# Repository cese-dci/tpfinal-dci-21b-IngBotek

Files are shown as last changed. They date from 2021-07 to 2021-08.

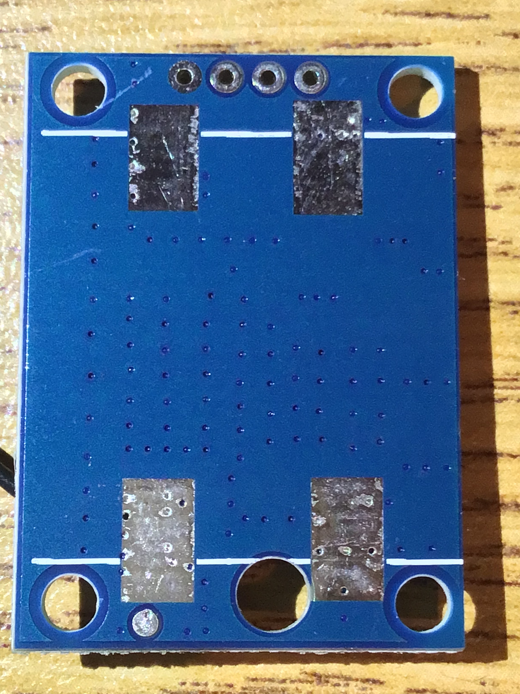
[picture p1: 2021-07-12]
doc/propuesta/Posterior.jpeg

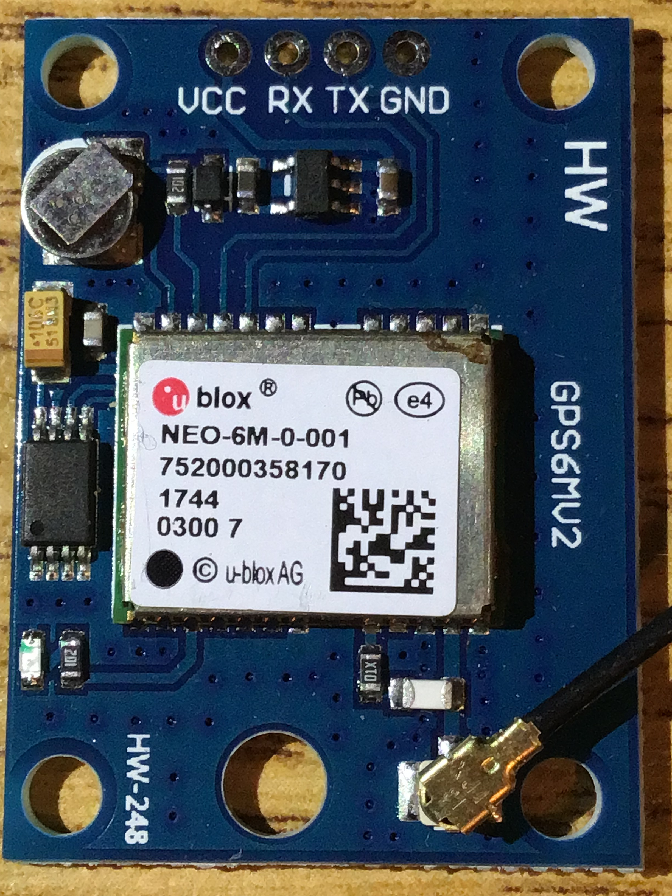
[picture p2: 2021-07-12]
doc/propuesta/Superior.jpeg

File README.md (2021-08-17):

## Trabajo práctico final de la asignatura DCI ##
Este repositorio contiene el trabajo práctico final para la asignatura de Diseño de Circuitos Impresos de la carrera de posgrado de FIUBA.

* Autor: Christian Canaan Castro Botek
* Título corto del trabajo:  Replica ublox NEO-6M GPS module
* Descripción: Módulo receptor que puede ser utilizado en cualquier aplicación que requiera geolocalización, cuenta con una antena de gran potencia, posee una memoria EEPROM para guardar datos y una batería para respaldar la configuración del módulo. Es compatible con Arduino, PIC, AVR, Raspberry y otros microcontroladores.

## Licencia de este trabajo ##
XXXMENCIONAR ACÁ LA LICENCIAXXX (Editar este párrafo) 
Y además colcar el archivo de texto de la misma en el directorio raíz.
Para este TP se pide que la licencia sea de hardware abierto.
Ver la sección "What license should I use?": https://www.oshwa.org/faq/

## Estructura del TP FINAL ##

Se propone y se pide utilizar la siguiente estructura.

* doc: Toda la información sobre el circuito, principalmente de autoría o procesamiento propio. Por ejemplo:
  * Notas de ingeniería propias.
  * Notas de aplicación propias.
  * Estudios previos, estado del arte, resumen de las investigaciones.
  * Notas con cálculos.
  * Dibujos adicionales.
  * Fotos de los prototipos.
  * Presupuestos, cotizaciones.
* info: Toda la iformación recolectada, principalmente de terceros, como por ejemplo:
  * Hojas de datos.
  * Notas de aplicación.
  * Info de productos comerciales.
  * Info en internet.
* pcb: Archivos de diseño esquemático y pcb.

Dependiendo la magnitud del proyecto, tendremos más o menos información en estos directorios. 
Revisar los README.md en cada directorio para conocer las pautas de cada uno para este TP.

NOTA: El alumno puede y debe borrar de este archivo todo lo que considere necesario, por ejemplo las aclaraciones del docente y esta misma nota.

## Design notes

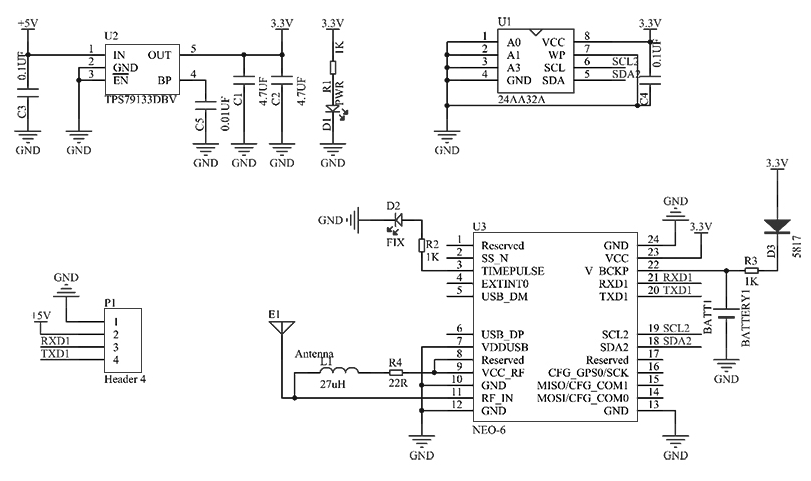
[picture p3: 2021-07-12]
doc/propuesta/Esquemático - NEO-6M.png

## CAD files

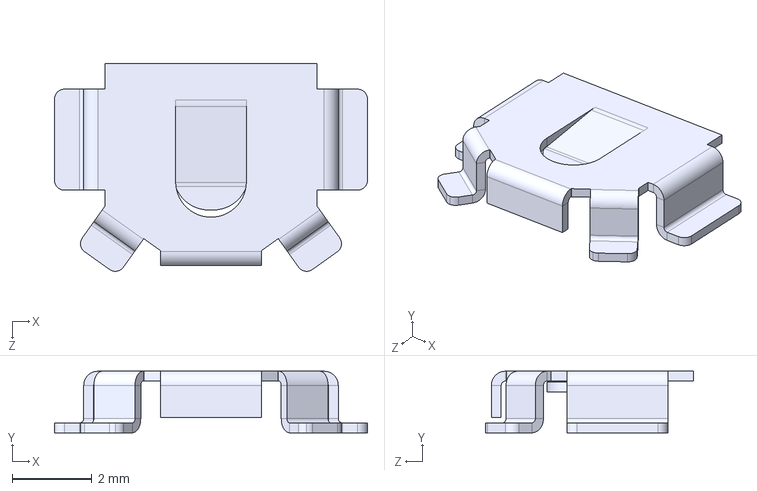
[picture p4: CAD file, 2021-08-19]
pcb/Replica_NEO_6M_GPS/3D_Models/BK-335-SM.step
7.87 x 1.55 x 5.22 mm

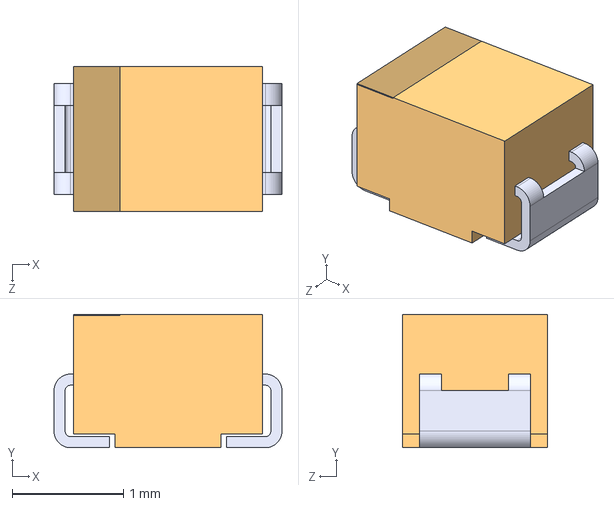
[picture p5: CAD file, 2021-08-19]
pcb/Replica_NEO_6M_GPS/3D_Models/TAJP156M006SNJ.STEP
2.05 x 1.20 x 1.30 mm

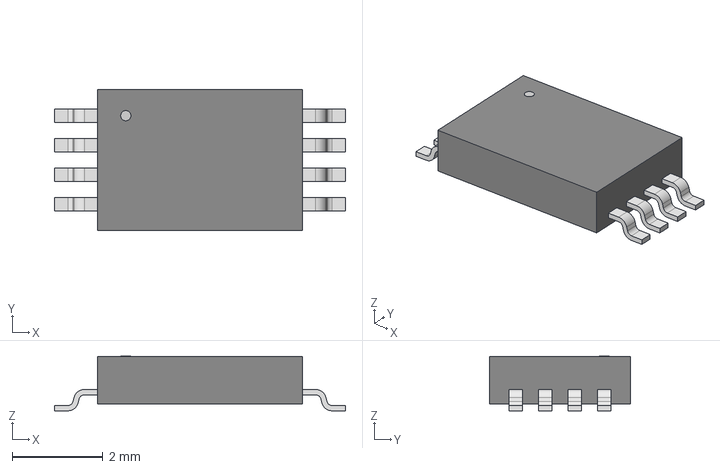
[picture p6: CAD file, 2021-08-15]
pcb/Replica_NEO_6M_GPS/3D_Models/TSSOP8_MC_MCH.step
6.40 x 3.10 x 1.20 mm

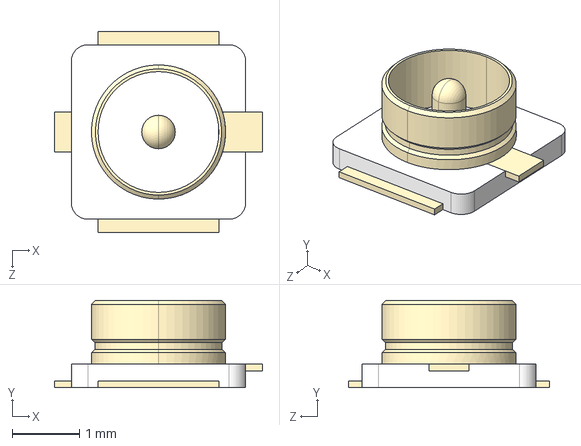
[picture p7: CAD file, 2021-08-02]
pcb/Replica_NEO_6M_GPS/3D_Models/CONUFL001-SMD-T.step
3.10 x 1.30 x 3.00 mm

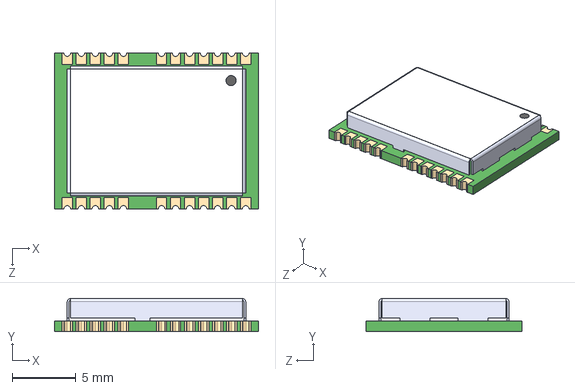
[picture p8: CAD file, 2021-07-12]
pcb/Replica_NEO_6M_GPS/3D_Models/NEO-6M-GPS.step
16.0 x 2.60 x 12.2 mm

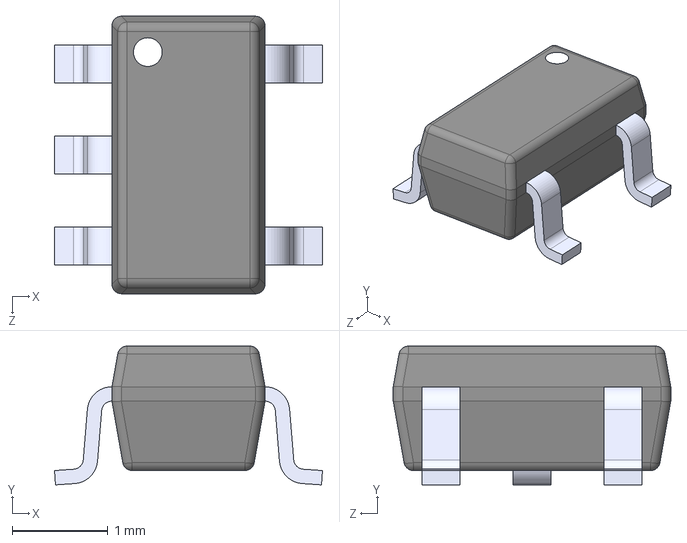
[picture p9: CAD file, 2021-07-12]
pcb/Replica_NEO_6M_GPS/3D_Models/TPS79133DBVR.STEP
2.80 x 1.45 x 2.90 mm

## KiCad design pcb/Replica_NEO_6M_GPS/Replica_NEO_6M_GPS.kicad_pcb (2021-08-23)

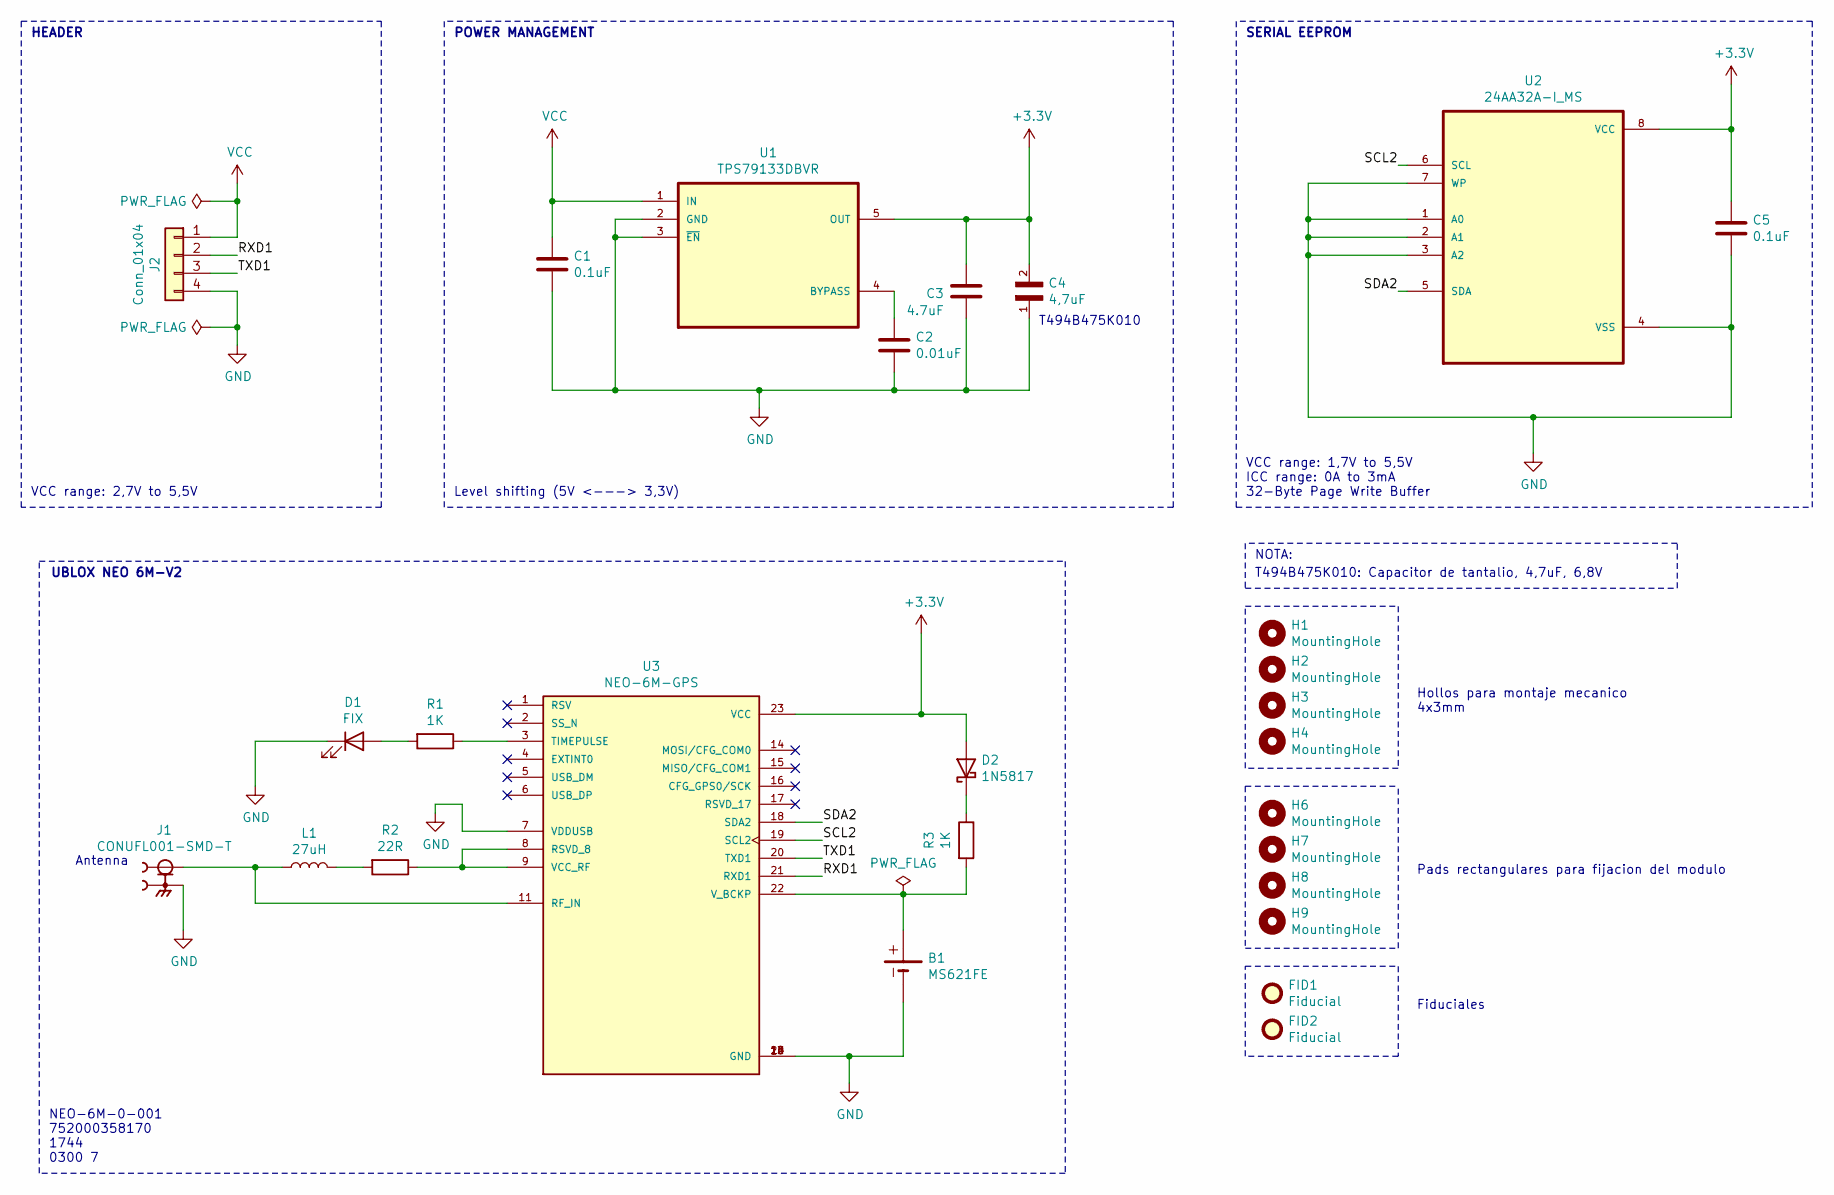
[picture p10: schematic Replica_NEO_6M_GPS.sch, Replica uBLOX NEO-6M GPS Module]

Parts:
B1: MS621FE
C1, C5: 0.1uF; C_0805_2012Metric_Pad1.18x1.45mm_HandSolder
C2: 0.01uF; C_0805_2012Metric_Pad1.18x1.45mm_HandSolder
C3: 4.7uF; C_0805_2012Metric_Pad1.18x1.45mm_HandSolder
C4: 4,7uF; CAPC2012X140N
D1: FIX; LED_0805_2012Metric_Pad1.15x1.40mm_HandSolder
D2: 1N5817; D_0805_2012Metric_Pad1.15x1.40mm_HandSolder
FID1, FID2: Fiducial; Fiducial_0.5mm_Mask1mm
H1, H2, H3, H4: MountingHole; MountingHole_3mm
H6, H7, H8, H9: MountingHole; MountingHole_3.5mm_Pad
J1: CONUFL001-SMD-T; LINX_CONUFL001-SMD-T; PARTREV B
J2: Conn_01x04; PinHeader_1x04_P2.54mm_Horizontal
L1: 27uH; L_0805_2012Metric_Pad1.15x1.40mm_HandSolder
R1, R3: 1K; R_0805_2012Metric_Pad1.20x1.40mm_HandSolder
R2: 22R; R_0805_2012Metric_Pad1.20x1.40mm_HandSolder
U1: TPS79133DBVR; SOT95P280X145-5N
U2: 24AA32A-I_MS; SOP65P490X110-8N
U3: NEO-6M-GPS; XCVR_NEO-6M-GPS; PARTREV R15

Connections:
+3V3: C3.1, C4.2, C5.1, D2.2 (A), U1.5 (OUT), U2.8 (VCC), U3.23 (VCC)
/RXD1: J2.2, U3.21 (RXD1)
/SCL2: U2.6 (SCL), U3.19 (SCL2)
/SDA2: U2.5 (SDA), U3.18 (SDA2)
/TXD1: J2.3, U3.20 (TXD1)
GND: B1.-, C1.2, C2.2, C3.2, C4.1, C5.2, D1.1 (K), J1.2, J1.3, J2.4, U1.2 (GND), U1.3 (~EN), U2.1 (A0), U2.2 (A1), U2.3 (A2), U2.4 (VSS), U2.7 (WP), U3.7 (VDDUSB), U3.10 (GND), U3.12 (GND), U3.13 (GND), U3.24 (GND)
unnamed: B1.+, R3.2, U3.22 (V_BCKP)
unnamed: C2.1, U1.4 (BYPASS)
unnamed: D1.2 (A), R1.2
unnamed: D2.1 (K), R3.1
unnamed: J1.1, L1.1, U3.11 (RF_IN)
unnamed: L1.2, R2.2
unnamed: R1.1, U3.3 (TIMEPULSE)
unnamed: R2.1, U3.8 (RSVD_8), U3.9 (VCC_RF)
VCC: C1.1, J2.1, U1.1 (IN)

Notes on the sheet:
Hollos para montaje mecanico 4x3mm
Antenna
HEADER
VCC range: 2,7V to 5,5V
POWER MANAGEMENT
Level shifting (5V <---> 3,3V)
SERIAL EEPROM
UBLOX NEO 6M-V2
T494B475K010
VCC range: 1,7V to 5,5V ICC range: 0A to 3mA 32-Byte Page Write Buffer
NEO-6M-0-001 752000358170 1744 0300 7
T494B475K010: Capacitor de tantalio, 4,7uF, 6,8V
NOTA:
Pads rectangulares para fijacion del modulo
Fiduciales

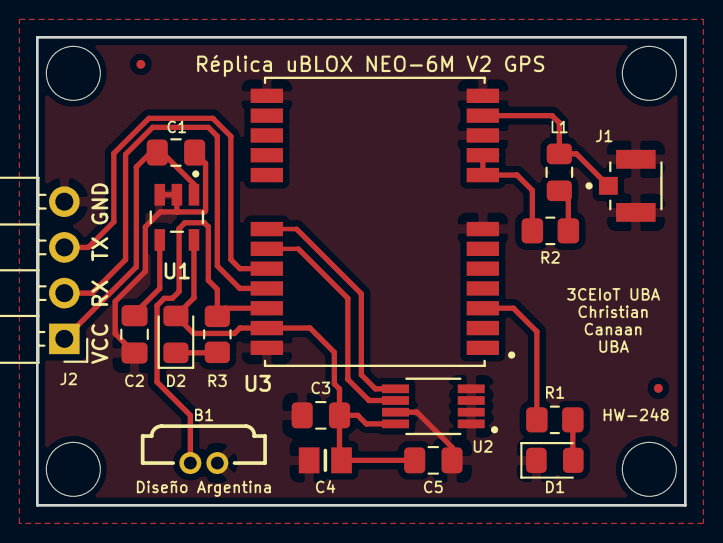
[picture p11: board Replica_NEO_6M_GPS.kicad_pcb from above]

Board: 2 copper layers, 36.0 x 26.0 mm, 27 parts (0 on the bottom side), 15 nets.

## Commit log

2021-07-12 Se cargan archivos de propuesta e info
    [Replica_NEO_6M_GPS.kicad_pcb, Replica_NEO_6M_GPS.sch]
2021-07-12 se agrega esquematico y librerias
    [Alimentacion.sch, Memoria.sch, NEO-6M-GPS.step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]
2021-07-12 se hicieron correcciones
    [Alimentacion.sch, Memoria.sch, NEO-6M.sch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]
2021-08-02 Se agregaron footprints y se hicieron correcciones menores
    [Alimentacion.sch, CONUFL001-SMD-T.step, Memoria.sch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]
2021-08-15 Se hicieron correcciones y se avanzo con el PCB
    [Alimentacion.sch, NEO-6M-GPS--3DModel-STEP-56544.STEP, NEO-6M.sch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]
2021-08-15 Se hicieron cambiaron los footprints de los LEDS D1,D2
    [Alimentacion.sch, NEO-6M.sch, Replica_NEO_6M_GPS.kicad_pcb]
2021-08-15 Se ajusto el margen para el componente U2
    [Replica_NEO_6M_GPS.kicad_pcb]
2021-08-15 Se hicieron correcciones menores
    [Replica_NEO_6M_GPS.kicad_pcb]
2021-08-17 Se acomodaron archivos y se hicieron retoques
    [Alimentacion.sch, CONUFL001-SMD-T.step, Memoria.sch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]
2021-08-17 se retoco el esquematico
    [Alimentacion.sch, Memoria.sch, NEO-6M.sch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]
2021-08-19 Se acomodaron directorios y se hicieron correcciones
    [BK-335-SM.step, CONUFL001-SMD-T.step, NEO-6M-GPS.step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]
2021-08-23 Se hiceron correcciones 23/08/2021
    [Replica_NEO_6M_GPS.kicad_pcb, Replica_NEO_6M_GPS.sch]

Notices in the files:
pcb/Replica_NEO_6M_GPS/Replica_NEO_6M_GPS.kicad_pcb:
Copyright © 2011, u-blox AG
